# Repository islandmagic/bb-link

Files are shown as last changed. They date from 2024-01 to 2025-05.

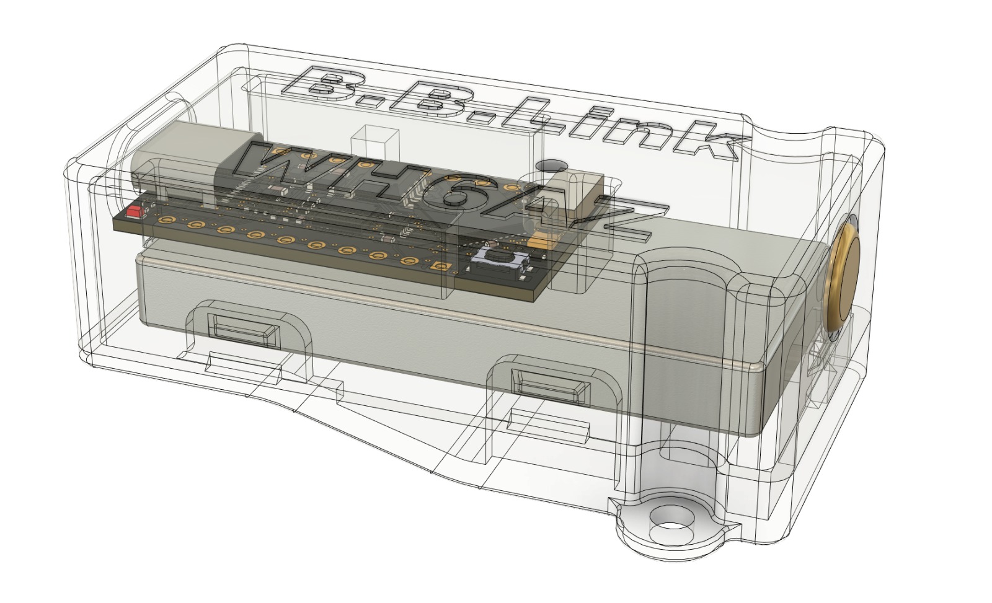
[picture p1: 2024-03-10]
enclosure/contribs/F4LFJ/BB-Link_case_01.jpeg

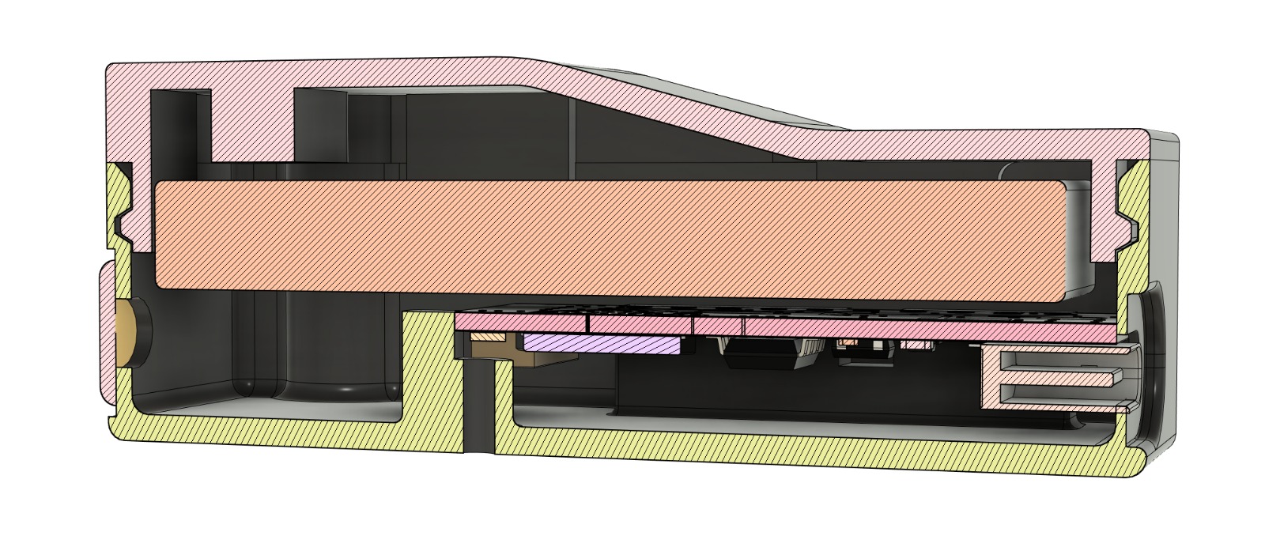
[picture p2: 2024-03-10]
enclosure/contribs/F4LFJ/BB-Link_case_06.jpeg

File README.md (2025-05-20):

<hr/>

### Psst… skip the soldering.

<a href="https://islandmagic.co/products/B-B-Link-Adapter-p629580960?utm_campaign=diy&utm_medium=web&utm_source=github">
              
</a>
              <br/>
 
### 👉 <a href="https://islandmagic.co/products/B-B-Link-Adapter-p629580960?utm_campaign=diy&utm_medium=web&utm_source=github">Check out</a> the sleek ready-made version that plugs directly into USB-C!

<hr/>

# B.B. Link, the BLE to Bluetooth Classic adapter for Kenwood TH-D74/5 Radios

Some devices, like the Kenwood TH-D75 radio only support Bluetooth Classic serial profile. iOS devices only support Bluetooth Low Energy (BLE). They are not compatible and as such, you can't pair those devices together. This code provides a way to create an adapter that can interface a device that exposes a serial profile over Bluetooth Classic, to an iOS device via BLE. Its main purpose is to enable iOS app that supports AX.25 packet like RadioMail or APRS.fi to use the TNC built in the radio as a modem.

For a detailed "how-to build" this adapter, watch this video: 

Watch the video (https://player.mux.com/SZQsZnBJDJf4GMUrTRxJ386tSpsIlRP02yfmXZr79TKg)

After you're done, come back and follow the instructions here as they are continually updated.

## Hardware

The adapter is based on the ESP32 microcontroller, which provides support for both Bluetooth Classic and Bluetooth Low Energy (BLE). There is specialized code tailored for the [TinyPICO](https://www.tinypico.com) development board, which serves as the standard implementation. This code can be altered to work with other ESP32-based boards as needed.

**Note: Compatibility is limited to ESP32 microcontroller. Boards like the TinyS3, which use the ESP32-S3 chip, do not support Bluetooth Classic. If you don't use the TinyPICO, make sure to choose a board that features the ESP32 microcontroller.**

### Material

1. TinyPICO [Buy](https://unexpectedmaker.com/shop.html#!/TinyPICO/p/577111313/category=154494282)
2. 600 mAh LiPo Battery model 602248 (6x22x48mm) [Buy](https://www.aliexpress.us/item/2251832520607268.html)
3. 3D Printed case
4. Brad fastener as touch button (8mm head)

### Power Options

The adapter can be powered via USB, such as through a USB adapter or a portable power bank, or alternatively, it can be connected to a LiPo battery for use on the go. The TinyPICO will charge the battery when plugged into USB.

### Capacitive Touch Button

The installation of a capacitive touch button is not required but recommended if you need an on/off switch while using a LiPo battery. To install, connect a wire to pin number 4 on the TinyPICO board; this will serve as the on/off control.

### Cases

You can 3D print a case to house the battery and the board. Here are a couple of option that attach via the mounting holes for the belt clip.

1. Horizontal

This is the orignal design from WH6AZ, functional but primitive. Can work as a stand alone box if you don't feel like attaching to the radio.

https://github.com/islandmagic/bb-link/tree/master/enclosure

2. Vertical

This design is a beautiful contribution from F4LFJ. It features a slick design that allows the case to attach vertically. There is enough clearance to insert and remove the battery from the radio.

https://github.com/islandmagic/bb-link/tree/master/enclosure/contribs/F4LFJ

## Software

1. Install Arduino IDE 2.x [https://www.arduino.cc](https://www.arduino.cc)
1. Add additional library source in Arduino IDE. Settings > Additional board manager URLs: `https://raw.githubusercontent.com/espressif/arduino-esp32/gh-pages/package_esp32_index.json`
1. Install the esp32 by Espressif Systems board library. This code has been tested with version 2.0.15.
1. Install the TinyPICO helper library
1. Install FreeRTOS library
1. Install ArduinoQueue library
1. Install ArduinoLog library
1. Clone this repo
1. Flash the code to the TinyPICO board
1. Download [B.B. Link Configurator](https://apps.apple.com/us/app/b-b-link-configurator/id6476163710) app on your phone
1. Download RadioMail on your phone [https://radiomail.app](https://radiomail.app)

### Rig Control

By default, the adapter will set the radio to KISS mode and automatically respond to RadioMail's instructions to switch frequencies, enabling seamless operation. If you prefer the adapter not to alter radio settings during use, toggle off the 'Control Frequency' option in the configurator app.

## Operating Instructions

### Powering On

1. Wake the adapter by briefly pressing the touch button. An amber light will indicate that it is awake.

### Pairing with a Radio (one time only)

1. Turn on adapter
1. Open B.B. Link Configurator app on your  phone
1. After a few seconds, `B.B. Link` appears in the list of nearby adapters. Select it.
1. Set the radio in Bluetooth discovery mode. Navigate to 'Menu -> Bluetooth -> Pairing Mode' on the radio.
1. Tap 'Paired Radio' on B.B. Link app
1. Wait a few seconds, the name of your radio should appear in the list. Select it.
1. After a few seconds a PIN prompt should appear on the radio. Press 'OK' to accept. This step is only necessary once; afterwards, the adapter will automatically try to reconnect with the radio.
1. Successful pairing is indicated by a breathing blue LED on the adapter.

### Pairing with iPhone or iPad

1. Make sure B.B. Link Configurator app is fully closed
1. Open the RadioMail app. Proceed to 'Settings -> KISS TNC Modem -> Default TNC'.
1. `B.B. Link` should be visible in the discovery screen.
1. Select `B.B. Link` and tap 'Done'.
1. Navigate to the connection screen and choose a packet station.
1. A solid blue LED on the adapter signals that RadioMail has connected. Red and green LEDs will flash to indicate data transmission and reception.

### Powering Off

- The adapter will shut off automatically after 5 minutes when not in use on battery power. It stays on indefinitely if USB power is detected.
- To manually turn off the adapter, press and hold the touch button until the LED blinks amber, then release.

### User Interface

#### Touch Button Functions

- **Short Press**: Wake the adapter or check the battery status when idle.
- **Long Press**: Turn off the adapter.

#### LED Indicator

The dotstar tri-color LED is used to indicate various states:

- 🟠: Idle, adapter waiting to pair
- 🔵 (slow flash): Adapter scanning for radio
- 🔵 (breathing): Idle, paired with radio
- 🔵: Ready, radio and iOS device paired
- 🟠 (fast blink): Shutting down

Data Activity:

- 🟢: Rx (Receiving)
- 🔴: Tx (Transmitting)
- 🟣: Rx/Tx (Both Receiving and Transmitting)

Error Conditions:

- 🔴 (fast blink): Low battery immediate shutdown
- 🔴 (slow flash): Fatal error, must reset

Battery Status Indicators:

- 🟢: Battery full
- 🟢 (fast blink): Battery low

#### Battery Indicator

The charge level of a LiPO battery can be difficult to determine without additional circuitry due to their non-linear discharge curve. A basic battery indicator is provided based on the battery voltage level:

1. Upon waking up, the adapter displays the battery level for a few seconds. A solid green light indicates the battery is considered full, while a flashing green light suggests the battery needs charging.
1. When the adapter is idle (indicated by an amber LED), a short tap will activate the battery level display.

### Battery Saver

To save energy, the adapter automatically enters a low-power sleep mode after a certain period of not being used, for instance, when no phone is connected, during which it consumes approximately 40 µA. While active, the adapter's power consumption is around 140 mA, allowing for continuous operation for up to 4 hours on a 600 mAh battery. In standby mode, with no active bluetooth connection, it uses about 80 mA. Additionally, the sleep feature is disabled when the adapter is connected to USB power, ensuring that the adapter can stay on for longer durations and can be used while it is being charged.

If the battery voltage falls to a critical level, the adapter will automatically shut down to prevent damage to the circuit.

### Factory Reset

You can reset the adapter to its default configuration. This will clear the list of previously paired devices and restoring default settings. Simply tap 'Reset Adapter' in the configurator app.

Alternatively, you can reset the adapter by connecting it to a computer. Here's how to do it:

1. Launch the Arduino IDE on your PC.
1. Connect the adapter to your PC using a USB cable.
1. Navigate to the Serial Monitor within the IDE.
1. Type `R` into the Serial Monitor and send the command.
1. Monitor the response in the Serial Monitor which will confirm the clearing of the previously paired devices.
1. After the process is complete, disconnect the adapter from your PC.

## Troubleshooting

* If the adapter connects to the radio but the radio does not transmit, check the TNC settings. Go to Menu > Configuration > Interface > KISS (983) and set it to Bluetooth.

## Known Issues

1. The ESP32 library is limited to discovering Bluetooth Classic devices exclusively prior to establishing any connections. After connecting with a device, the discovery capability is no longer available. To initiate a new scan, the adapter must be rebooted. If you intend to pair with a different radio, ensure that the radio previously paired with is turned off before powering on the adapter. If not, the adapter will automatically re-establish a connection with the previously paired radio, preventing it from discovering new radios.

## How to Contribute

This project is open source, so everyone's contribution is welcome. Here's a quick guide to get started:

* **Share**: If you build your own adapter, share it online! Post photos, write a blog post, or create a tutorial video to show others how it's done.
* **Update Documentation**: Help improve or correct the documentation. Fork the repo, make your updates, and submit a pull request.
* **Submit Change Requests**: If you're developing a new feature or bug fix, fork the repository, create a new branch for your changes, and submit a pull request with a clear description of your modifications.
* **Write Good Issue Reports**: If you encounter bugs or have feature suggestions, please submit an issue report with a clear title, a detailed description, and steps to reproduce the issue if it's a bug.

The source code for the [Configurator](https://github.com/islandmagic/ios-bblink-config) app is available as well.

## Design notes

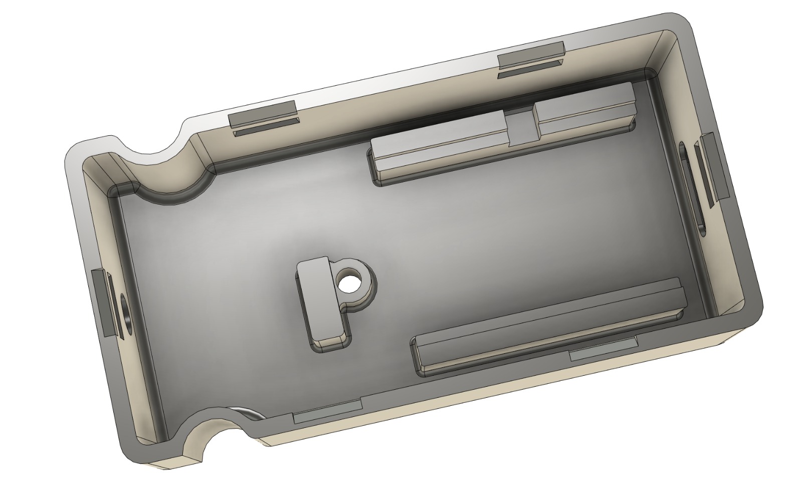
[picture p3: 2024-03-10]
enclosure/contribs/F4LFJ/BB-Link_case_03.jpeg

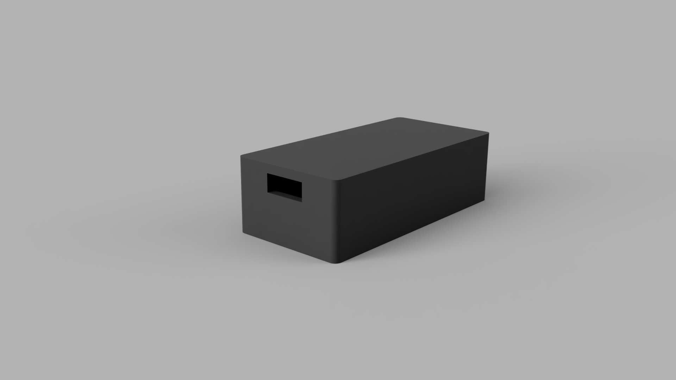
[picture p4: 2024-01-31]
enclosure/B.B. Link enclosure.jpg

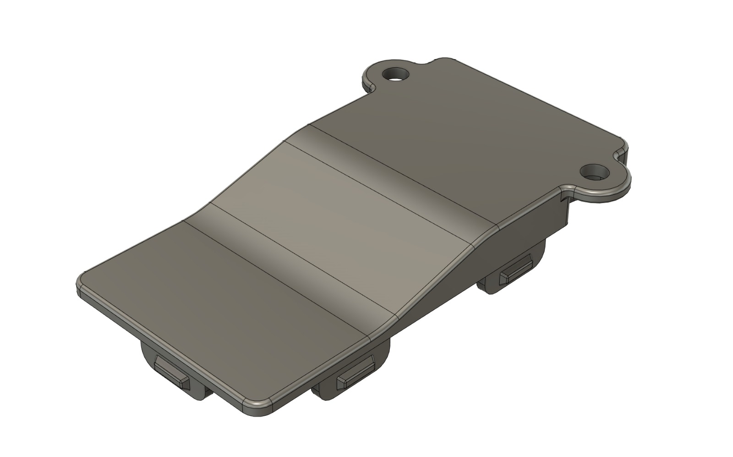
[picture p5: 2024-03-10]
enclosure/contribs/F4LFJ/BB-Link_case_04.jpeg

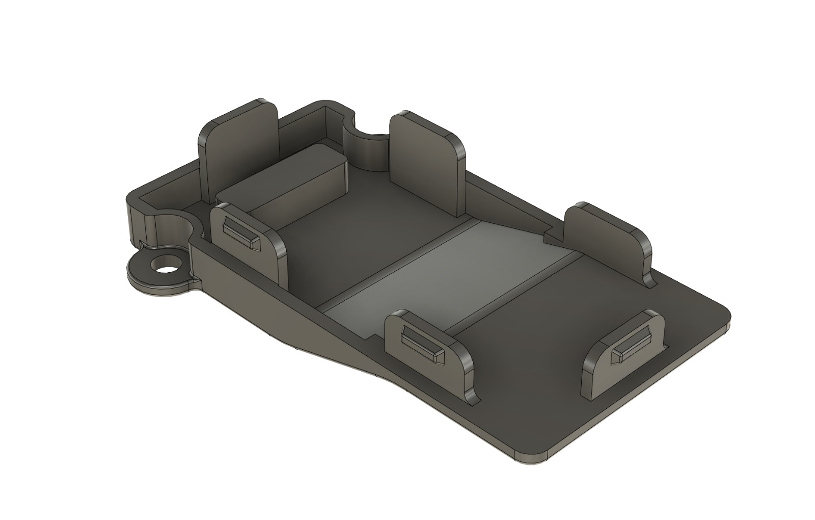
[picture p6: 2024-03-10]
enclosure/contribs/F4LFJ/BB-Link_case_05.jpeg

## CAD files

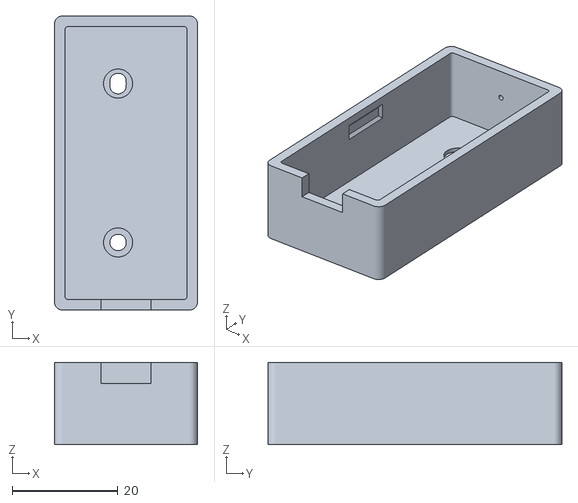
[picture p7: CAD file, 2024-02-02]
enclosure/B.B. Link v3 - Enclosure.stl
27.0 x 55.5 x 15.5

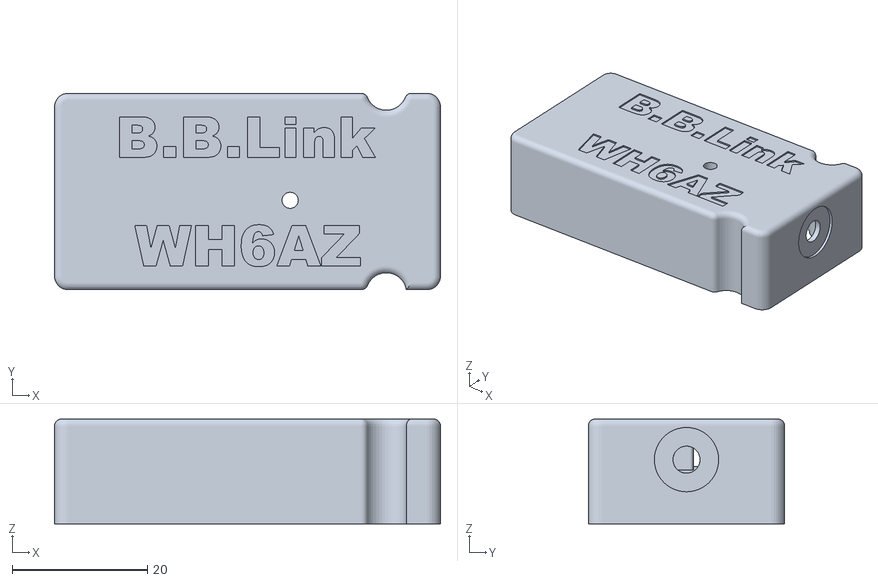
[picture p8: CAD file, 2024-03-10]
enclosure/contribs/F4LFJ/BB-link part A v5.stl
57.0 x 29.0 x 15.5

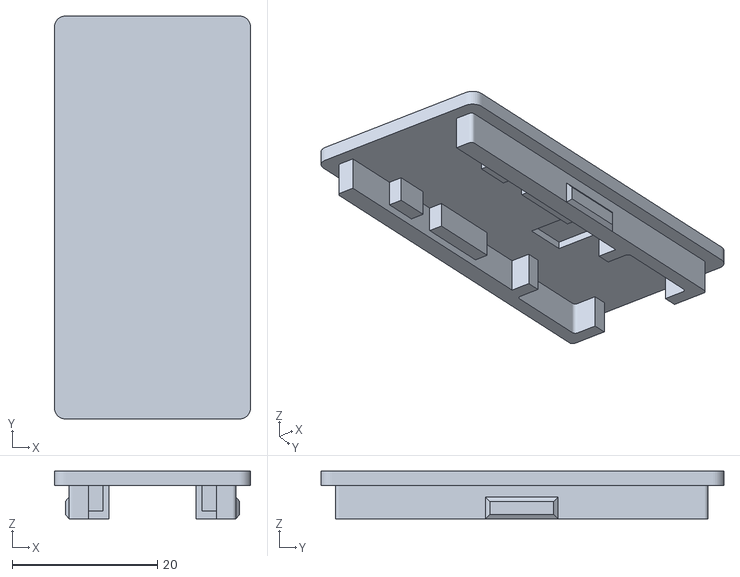
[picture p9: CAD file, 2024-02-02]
enclosure/B.B. Link v3 - Lid.stl
27.0 x 55.5 x 6.56

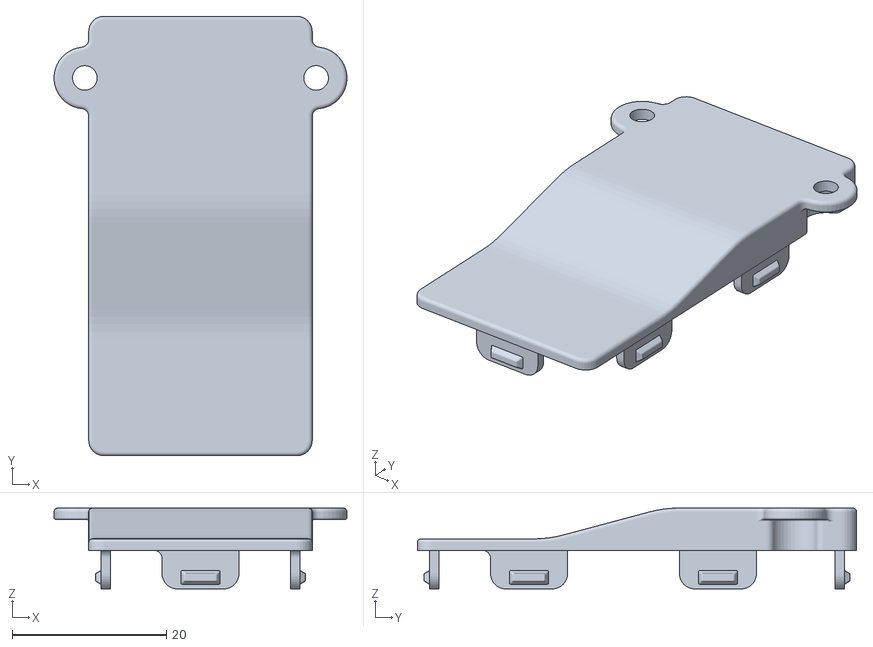
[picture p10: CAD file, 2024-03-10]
enclosure/contribs/F4LFJ/BB-link part B v5.stl
38.0 x 57.0 x 10.5

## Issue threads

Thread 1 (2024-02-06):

enclosure STL designs

swiftraccoon, 2024-02-06:
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

Note the size in mm.

commit 33436c0

georges, 2024-02-06:
The enclosure that also double as a swimming pool.

I'm not seeing that. Did you make sure your user preferences are set to mm?

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

swiftraccoon, 2024-02-06:
Yeah, the settings were correct.

I see the problem now, however. You cannot right click "Save Link As". You must go the file in GitHub directly and then click the "Download Raw File" button. My apologies!

Closed 2024-02-06.

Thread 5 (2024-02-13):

B.B.Link Configurator Update Firmware Link

giminok, 2024-02-13:
In B.B.LinkConfigurator app - it shows the Firmware Version as 0.7.3.  The "Update Firmware" link is active below it.

When "Update Firmware" link is pressed, the dialog shows "Update Firmware to 0.7.2".

As it shows the adapter is on 0.7.3 the firmware update isn't needed so Update Firmware link should be disabled?   Only adding this if that can cause a problem otherwise do not think it matters once a radio is paired.

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

georges, 2024-02-14:
Thanks for the detailed report. There are a few things at play here.

0. The current OTA firmware is set to 0.7.2

1. There is a toggle in Settings -> B.B. Link Configurator -> Experimental that allows you to toggle a Beta channel for firmware updates. The Beta channel will post pre-release version as they are being tested. This allows me to test OTA update without disrupting anything. Usually that channel will have one version up, for instance now it's 0.7.3

2. Because of the Beta channel, I wanted a way to allow downgrade to released firmware. For example someone may try the Beta channel, realize it's breaking something and need to go back down. As such, I decided to allow firmware upgrade as long as the installed version is different than the available OTA version (could be upgrade or downgrade)

I could clean up the UI to be a more descriptive to inform the user they will downgrade in that case.

georges, 2024-02-14:
And to answer the rest of your question, firmware upgrade should not affect radio pairing, unless of course some new code gets introduce that would require a repairing for some reason.

giminok, 2024-02-14:
@georges Thank you for a quick reply.  The downgrade makes a lot of sense.  Appreciate the details.

Closed 2024-02-14.

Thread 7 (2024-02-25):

TinyPICO TP01 USB C

Thuff256, 2024-02-25:
I flashed my TinyPICO with the Mac version of the Arduino IDE 2.3.3 and I got what looked like it downloaded to work.

Leaving...
Hard resetting via RTS pin...

Unfortunately, the amber LED never came on indicating the TinyPICO reset and rebooted.  When I removed the USBC cable and reapplied it would not come out of the state it was stuck in.  I tried two more times to flash the board with no change.

It did say Installed ArduinoQueue: 1.2.5
FreeRTOS:11.0.1-5
TinyPICO Helper Library:1.4.0
esp32.2.0.14

I am sure I missed something so please let me know what I can do to get this working.

If you need anything else please let me know to get this working.

Tim KM4ESU

Thuff256, 2024-02-25:
I missed the ArduinoLog so I added it and flashed the board.  I check the serial Monitor and this is what I saw.
����������������������������������������������������������������������������������������������
I am set a 115200 Baud.

georges, 2024-02-25:
Yes the board should come up at 115200 baud. If you're seeing gibberish it means that the speed is not setup properly, perhaps the code is not starting. Try to change the serial monitor speed down to 9600 baud. Press reset on the board and see if you get some output. It should show you what's happening on the board, either the default program running, or something else.

Also, please include the complete output of the flashing window just in case something is not working correctly during that phase.

Thuff256, 2024-02-25:
Reset got the serial to work at 115200.  Please let me know what to do next.

Thank you!
Tim

rst:0x1 (POWERON_RESET),boot:0x13 (SPI_FAST_FLASH_BOOT)
configsip: 188777542, SPIWP:0xee
clk_drv:0x00,q_drv:0x00,d_drv:0x00,cs0_drv:0x00,hd_drv:0x00,wp_drv:0x00
mode:DIO, clock div:1
load:0x3fff0030,len:1344
load:0x40078000,len:13964
load:0x40080400,len:3600
entry 0x400805f0

georges, 2024-02-25:
This is what you should see on a properly flashed TinyPICO

```
rst:0x1 (POWERON_RESET),boot:0x13 (SPI_FAST_FLASH_BOOT)
configsip: 188777542, SPIWP:0xee
clk_drv:0x00,q_drv:0x00,d_drv:0x00,cs0_drv:0x00,hd_drv:0x00,wp_drv:0x00
mode:DIO, clock div:1
load:0x3fff0030,len:1344
load:0x40078000,len:13964
load:0x40080400,len:3600
entry 0x400805f0

 ___   ___     _    _      _
| _ ) | _ )   | |  (_)_ _ | |__
| _ \_| _ \_  | |__| | ' \| / /
|___(_)___(_) |____|_|_||_|_\_\

Booting up B.B. Link v0.7.4 on TinyPICO v3.0

Heap free: 232100, usage: 11 %
Flash size: 1190704, total: 1310720, usage: 90 %
Log level: INFO
```

It appears that your board is not executing the setup() properly for some reason. Maybe it's defective? Have you tried flashing as simple hello world and see if it works?

Thuff256, 2024-02-25:
I tried two different boards with the same result. They came from the Unexpected Maker in Australia. I practiced good ESD too. I guess I can order 2 more to see but the lights come on and its not dead.

georges, 2024-02-25:
Mmm, I'd say it's probably something else. When you say the lights come on, are you talking about the top left blue and the top right blinking yellow?

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

And from what you said earlier, the tri-color on the bottom is not coming on for you?

georges, 2024-02-25:
And just to confirm, when you flashed you selected TinyPICO and the wchusbserial port?
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

Thuff256, 2024-02-25:
Yes, the bottom blue and amber come on but the tri-color does not.  This is the same on the board you show.  I do have an earlier USB-C as well but until I know these two are dead I will wait in it.  The computer is an M1 Mac with an Apple USBC Thunderbolt data cable to program the board.

georges, 2024-02-25:
Can you try to remove that line

https://github.com/islandmagic/bb-link/blob/51684739e3f17b9a8a742f20d39347f30b24f7e4/src/bb-link/bb-link.ino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

and reflash?

Thuff256, 2024-02-25:
Yes, that is the board and port note the amber LED by the USB-C connector is blinking and the blue is on.

Thuff256, 2024-02-25:
rst:0x1 (POWERON_RESET),boot:0x13 (SPI_FAST_FLASH_BOOT)
configsip: 188777542, SPIWP:0xee
clk_drv:0x00,q_drv:0x00,d_drv:0x00,cs0_drv:0x00,hd_drv:0x00,wp_drv:0x00
mode:DIO, clock div:1
load:0x3fff0030,len:1344
load:0x40078000,

georges, 2024-02-26:
In your Arduino IDE, find the file named `bb-link.ino` and scroll to line 24

Thuff256, 2024-02-26:
I tried to edit line 24 but the code is read-only.  I am not sure if I can pull it into an editor and edit then past the whole thing into the Arduino IDE.

Tim

Thuff256, 2024-02-26:
I did test the third board all USB-C but that one is older none seem to work.  I am not sure what I am doing wrong but I do hope to get them working.  I have 2 D74 that need this one for traveling the other home.

I hope we can find out why they do not work.

Tim

georges, 2024-02-26:
There should not be anything involving GitHub, you just need to edit your local file from within the Arduino IDE.

Thuff256, 2024-02-26:
This may be the problem I can't find the local file?  it should be in /Users/timhuffaker/Documnets/Aruino I do see the libraries but not the sketch file.  Is it hidden?

georges, 2024-02-26:
The ArduinoIDE should have tabs open with files.

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

If bb-link.ino does not show, use the 3-dot menu to open it.

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

Thuff256, 2024-02-26:
Well, I found the problem your GetHub file is not loading in the download and there is nothing in the three dots.  I did follow your youtube and copied the file but I do not know why the file is not loaded.  Should I click the raw button and copy the file?   This is what I do for Raspberry Pi's to download code.

georges, 2024-02-26:
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

1. On GitHub, click green button, select download zip.
2. Expand the zip in your local directory
3. Double click `bb-link.ino` in `bb-link-master/src/bb-link` folder
4. Arduino IDE should open an load all the files for you

You probably flashed an empty file to the board, so try to flash these file first before trying to remove the line I had suggested.

Thuff256, 2024-02-26:
Success I have an amber LED.  Not to continue testing and add the battery.  For you and some humor, my son came in and I asked him for help.  He did what you showed before you showed it and that got it working.  Then I read your post and LOL.

Thank you for your help!
Tim

Closed 2024-02-26.

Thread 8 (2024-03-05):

Compilation error: ArduinoLog.h: No such file or directory

F4LFJ, 2024-03-05:
Hi Georges,

Not an issue anymore but here is what I have encountered at the first compilation:

During the first compilation I've got the following error:
Compilation error: ArduinoLog.h: No such file or directory

Line 15 of the ino file reference it: #include <ArduinoLog.h>

The installation of the ArduinoLog library is not mentioned in your video.
So I've installed the v1.1.1 by Thijs Elenbaas

I was able to compile and upload the file to the board.
The BB-link apps see the board, it works!
I just wait few days to receive my Th-D75.

Thanks for this great job!

73, Claude, F4LFJ

georges, 2024-03-09:
Thanks Claude. Yes the logging has been added since the video. The README has been updated so always a good idea to check that too. Glad you got it running.

F4LFJ, 2024-03-09:
Great! Thanks for the feedback George!

Closed 2024-03-09.

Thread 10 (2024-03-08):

TH-D75E doesn't transmit

F4LFJ, 2024-03-08:
Hello,

I've used the components described in this repository and have compiled the latest ino file.
On my phone the firmware version is described as v0.7.4

Radiomail/BB-link would switch the HT to the selected frequency and Kiss mode but the TH-D75 is not transmitting.
I can see the led on the Tinypico board blinking red but no tranmission on the HT.

Once the transmission request cancelled, BB-link restore the original frequency and mode.

TH-D75E
Tinypico USB-C
iPhone 11, iOS 17.3.1
Radiomail 1.3.1 (7)
BB-link 1.0.1 (2), firmware 0.7.4

73,
Claude, F4LFJ

georges, 2024-03-09:
If the adapter connects to the radio but the radio does not transmit, check the TNC settings.
Go to Menu > Configuration > Interface > KISS (983) and set it to Bluetooth.

F4LFJ, 2024-03-09:
Thanks, it was that!
All working know...just have to find a station that I can work with.

By the way, I made a case that can be mounted at the place on the belt clip.
I can share the STL files.

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

georges, 2024-03-10:
Great to hear you're up and running. Fantastic job on the case. I had originally thought of going vertical, but clearly lack the skills to make it be as streamline as your design.

Do you mind sending a pull request with the .stl files in the enclosure directory and I'll be more than happy to merge this in.

F4LFJ, 2024-03-10:
Great you like the case!
No sure how to pull a request to add stl files only, so you should have received a email at your winlink address that contain a link to a dropbox folder.

Regards,
Claude

georges, 2024-03-10:
Link did not seem to have gone thru. Can you post it here? Thanks. On Mar 10, 2024, at 03:10, F4LFJ ***@***.***> wrote:
Great you like the case!
No sure how to pull a request to add stl files only, so you should have received a email at your winlink address that contain a link to a dropbox folder.
Regards,
Claude

—Reply to this email directly, view it on GitHub, or unsubscribe.You are receiving this because you commented.Message ID: ***@***.***>

F4LFJ, 2024-03-10:
Ok,this link should work:
[https://www.dropbox.com/scl/fo/olg7sb9cd9zcofyi6ggig/h?rlkey=3vxm2wyfdxv4gsjwn9tiy6y8t&dl=0](url)

georges, 2024-03-10:
Perfect. I've updated the repo with your files. I'm going to have to print one of those, they look cool. Merci Claude!

F4LFJ, 2024-03-11:
De rien! Eventuellement je peux t'envoyer une paire de ses boitiers.

Closed 2024-03-10.

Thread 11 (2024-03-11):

Feature Request: Output TX/RX Pakets via serial console

9V1LH, 2024-03-11:
Aloha from Singapore!

For debugging purposes, it would be beneficial if the received and transmitted packets were sent to the serial output.

73 & 55 de Stephan 9V1LH / DG1BGS

georges, 2024-03-15:
What format would you expect the packet to be in? KISS frames in hex format?

9V1LH, 2024-03-15:
In the best case it would show the packets in a readable format like the raw packets you would see in the aprs.fi app

georges, 2024-03-17:
That would require needing to decode AX.25 protocol to interpret the payload. Fun, but maybe overkill for this adapter. What would you expect to get that you can't get in aprs.fi?

9V1LH, 2024-03-22:
I agree. I had another idea and for this, I would also need to decode the AX.25 protokoll. However, I wasn't paying too much attention and thought that the radio already sent the KISS packets which could be easily been written to the serial output. Maybe I take a closer look at it when I have some spare time.

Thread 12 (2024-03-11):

Feature Request: Convert Raw-Pakets to KISS-Pakets

9V1LH, 2024-03-11:
Aloha from Singapore!

I have another use case where I want the TH-D74 to remain in APRS standalone mode. However, in this mode, you can still output the raw packets via Bluetooth. It would be great if we could convert them into KISS packets and send them to the aprs.fi iOS app to continue displaying the received stations on the map.

73 & 55 de Stephan 9V1LH / DG1BGS

georges, 2024-03-15:
Interesting idea. I'll have to research this some more. However right now, when a device connects to B.B. Link via BLE, it automatically puts the radio in KISS mode because presumably a client is wanting to talk to the TNC. There would need some extra logic to make this conditional.

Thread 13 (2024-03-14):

feature request: M5StickC Plus support

fanlessfan, 2024-03-14:
Hello,

Could we add support for M5StickC Plus (ESP32-PICO-D4, with battery, buttons and screen)?

https://shop.m5stack.com/products/m5stickc-plus-esp32-pico-mini-iot-development-kit

thx
VA3EMQ

fanlessfan, 2024-03-14:
or add support for Atom Lite (Infra-Red LED, RGB LED, buttons) and Atom Matrix
https://shop.m5stack.com/products/atom-lite-esp32-development-kit
https://shop.m5stack.com/products/atom-matrix-esp32-development-kit

georges, 2024-03-15:
The M5StickC looks like an interesting all in one device. I don't have access to any of these devices, but if someone wants to open a pull request with proper support, I'll be happy to review.

fanlessfan, 2024-04-03:
Is there anyone can update the code to add the support for M5StickC Plus? Here is the schematic [https://m5stack.oss-cn-shenzhen.aliyuncs.com/resource/docs/schematic/Core/M5StickC_Plus/StickC_Plus_20200616.pdf](url)

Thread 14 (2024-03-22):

ArduinoLog.h: No such file or directory

rodzillanh, 2024-03-22:
when I verify I get to following error

D:\downloads\bb-link-master\bb-link-master\src\bb-link\bb-link.ino:15:10: fatal error: ArduinoLog.h: No such file or directory
 #include <ArduinoLog.h>
          ^~~~~~~~~~~~~~
compilation terminated.
exit status 1

Compilation error: ArduinoLog.h: No such file or directory

rodzillanh, 2024-03-22:
I figured it out

Closed 2024-03-22.

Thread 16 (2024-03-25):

TinyPICO board sleeping even when USB-C powered

ftmiranda, 2024-03-25:
Hello,
I followed this YouTube video https://www.youtube.com/watch?v=xLze6qDOLww&t=1127s and the solution proposed works extremely well.
Since I did not want to bother with the internal battery, I decided just to power the board with the USB-C. All works well, until you power off your D75, close the RadioMail on your iPhone and you keep the TinyPICO board powered by a large PowerBank... after a while, the board will enter in some sort of sleep mode. If I power back on my D75, and open the RadioMail, try to connect using packet.... nothing... the connection times out. If I unplug the USB-C and plug it again, after a few seconds I can re-check my email using RadioMail and all works great again.
Is there any way to prevent the board from sleeping at all when powered by the USB-C? Thank you

georges, 2024-03-25:
Can you plug the TinyPICO into a computer instead of power bank and open the serial console (easiest is to open in ArduinoIDE). After a while, you should see something like:

```
I: Idle for 300 s
I: On USB power, stay awake
```

ftmiranda, 2024-03-25:
Something I  noticed, I had a firmware update today, 0.74-> 0.75
After this update, I left the board connected to a power bank for hours, then I turned on my D75, after 5 seconds it connected to the pico board, and RadioMail just worked. Not sure if the firmware update did the trick or if I had a glitch before, but now it seems to work just fine!! Thank you

Closed 2024-03-26.

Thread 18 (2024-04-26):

Constantly losing BLE connection

2e0wkw, 2024-04-26:
In the B.B.Link app as soon as i move away from the page that shows the paired device the app reports that it has lost BLE connection. I am sure it hasn't.

E.G i connect my iPhone and TH-D75 and go to aprs.fi to send a message when i return to B.B.Link app it reports that it has lost the BLE connection

Setup:
TinyPico with latest firmware built via Arduini IDE 2.3.2 and esp32 2.0.11
TH-D75
iPhone 14 Pro with IOS 17.4.1

georges, 2024-04-28:
It's by design. With BLE, there can only be one application connected. The B.B. Link configurator app is meant to only be run seldomly to setup pairing with a radio. When the app looses focus, it automatically disconnects so that another app (APRS.fi in your case) can connect.

Closed 2024-05-30.

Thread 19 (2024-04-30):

can't get the TinyPICO to work

wptracy, 2024-04-30:
I have Arduino EDI 2.3.2 installed on the PC.

The sketch that is created is sketch_apr29a, but I don't know how it got that name.

I've got a paperclip connected to pin 4, but touching it long or short touch doesn't do anything.

I don't have a battery connected, but I do have the USB-C cable connecting the TinyPICO to the PC.

I figured that should power the board like the battery would.

I've got the following libraries installed but can't get the TinyPICO to work.
The amber light near the reset button and antenna, never comes on.
The blue light near the USB-C connector is bright and steady.
The amber light near the USB-C connector is dim and flashing (fast).

Here are the installed libraries:
esp32 by Espressif Systems 2.0.15
TinyPICO Helper Library by UnexpectedMaker 1.4.0
FreeRTOS by Richard Barry <info@freertos.org> 11.1.0.0
ArduinoQueue by Einar Amason by <einsiarna@gmail.com> 1.2.5
ArduinoLog by Thijs Elenbaas 1.1.1

I've compiled and uploaded to the TinyPICO and here is the log Output:
```
Sketch uses 257017 bytes (19%) of program storage space. Maximum is 1310720 bytes.
Global variables use 21168 bytes (6%) of dynamic memory, leaving 306512 bytes for local variables. Maximum is 327680 bytes.
esptool.py v4.5.1
Serial port COM3
Connecting....
Chip is ESP32-PICO-D4 (revision v1.1)
Features: WiFi, BT, Dual Core, 240MHz, Embedded Flash, VRef calibration in efuse, Coding Scheme None
Crystal is 40MHz
MAC: 64:b7:08:90:a3:14
Uploading stub...
Running stub...
Stub running...
Changing baud rate to 921600
Changed.
Configuring flash size...
Erasing flash (this may take a while)...
Chip erase completed successfully in 1.7s
Compressed 18992 bytes to 13110...
Writing at 0x00001000... (100 %)
Wrote 18992 bytes (13110 compressed) at 0x00001000 in 0.3 seconds (effective 483.5 kbit/s)...
Hash of data verified.
Compressed 3072 bytes to 146...
Writing at 0x00008000... (100 %)
Wrote 3072 bytes (146 compressed) at 0x00008000 in 0.0 seconds (effective 837.9 kbit/s)...
Hash of data verified.
Compressed 8192 bytes to 47...
Writing at 0x0000e000... (100 %)
Wrote 8192 bytes (47 compressed) at 0x0000e000 in 0.1 seconds (effective 1185.7 kbit/s)...
Hash of data verified.
Compressed 257376 bytes to 139364...
Writing at 0x00010000... (11 %)
Writing at 0x0001ddb1... (22 %)
Writing at 0x00024e5b... (33 %)
Writing at 0x0002a0d4... (44 %)
Writing at 0x0002f754... (55 %)
Writing at 0x000384cf... (66 %)
Writing at 0x000410ec... (77 %)
Writing at 0x000466ff... (88 %)
Writing at 0x0004bf37... (100 %)
Wrote 257376 bytes (139364 compressed) at 0x00010000 in 2.3 seconds (effective 905.9 kbit/s)...
Hash of data verified.

Leaving...
Hard resetting via RTS pin...
```

wptracy, 2024-04-30:
Never mind.  I figured it out.
Download bb-link-master.zip.
uncompress it
Change directory to src/bb-link
Double click on bb-link.ino to install it.

wptracy, 2024-04-30:
I figured it out.  see my comment above

Closed 2024-04-30.

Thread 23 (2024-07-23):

“nil” and SSI?

Beavxx, 2024-07-23:
I got it all working. Went back to it later and the Configurator App no longer shows “BB Link” and SSI; it shows “nil” and SSI.

Re-flashed several times. Same. Not sure what caused it to go from working to “nil”

This is great; thank you for sharing this.

Thank you in advance for any help you can offer on this issue.

Beavxx, 2024-07-23:
I flashed a second TinyPico I had and it works fine. Perhaos a bad board? Odd.

Beavxx, 2024-07-24:
The build works great. Not sure why the first board doesn’t work. Thank you for sharing this, it was a lot fun and a great companion for the D74 and Radiomail.

Beavxx, 2024-07-24:
I’m going with bad dev board. Closing.

tan js

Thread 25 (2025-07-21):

Compilation error: conversion from 'String' to non-scalar type 'std::string' {aka 'std::__cxx11::basic_string<char>'} requested

agflyguy, 2025-07-21:
Getting a compile error with newer versions of the ESP32 library by Espressif.   Version 2.0.17 compiles the code without errors, but anything from 3.0.0 to 3.2.1 exhibits the error. Adapter.cpp & Bridge.cpp are referenced by the error.

I am just getting the environment setup while waiting for my boards.  Not sure if using 2.0.17 ESP32 libray will cause any issues with a working board.

These errors are produced using the Verify function in the 2.3.6 IDE.

XX/Downloads/bb-link-master/src/bb-link/Adapter.cpp: In member function 'virtual void Adapter::onWrite(BLECharacteristic*)':
XX/Downloads/bb-link-master/src/bb-link/Adapter.cpp:274:49: error: conversion from 'String' to non-scalar type 'std::string' {aka 'std::__cxx11::basic_string<char>'} requested
  274 |   std::string rxData = pCharacteristic->getValue();
      |                        ~~~~~~~~~~~~~~~~~~~~~~~~~^~
XX/Downloads/bb-link-master/src/bb-link/Bridge.cpp: In member function 'bool Bridge::initBTC()':
XX/Downloads/bb-link-master/src/bb-link/Bridge.cpp:178:12: error: 'class BluetoothSerial' has no member named 'setPin'
  178 |   btSerial.setPin("0000");
      |            ^~~~~~
XX/Downloads/bb-link-master/src/bb-link/Bridge.cpp: In member function 'virtual void Bridge::onWrite(BLECharacteristic*)':
XX/Downloads/bb-link-master/src/bb-link/Bridge.cpp:715:50: error: conversion from 'String' to non-scalar type 'std::string' {aka 'std::__cxx11::basic_string<char>'} requested
  715 |   std::string txValue = pCharacteristic->getValue();
      |                         ~~~~~~~~~~~~~~~~~~~~~~~~~^~
exit status 1

Compilation error: conversion from 'String' to non-scalar type 'std::string' {aka 'std::__cxx11::basic_string<char>'} requested

Closed 2025-09-22.

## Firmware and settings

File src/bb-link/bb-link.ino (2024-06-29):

/*
  (c) 2024 Island Magic Co. All Rights Reserved.

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
  This program is distributed in the hope that it will be useful,
  but WITHOUT ANY WARRANTY; without even the implied warranty of
  MERCHANTABILITY or FITNESS FOR A PARTICULAR PURPOSE.  See the
  GNU General Public License for more details.
*/

#include <ArduinoLog.h>
const char *logLevels[] = {"OFF", "FATAL", "ERROR", "WARNING", "INFO", "TRACE", "VERBOSE"};

#include "Adapter.h"
Adapter *adapter = nullptr;

void setup()
{
  // Slow down to save power
  setCpuFrequencyMhz(80); // 240, 160, 80

  Serial.begin(115200);
  delay(1000);

  // LOG_LEVEL_FATAL, LOG_LEVEL_ERROR, LOG_LEVEL_WARNING, LOG_LEVEL_INFO, LOG_LEVEL_TRACE, LOG_LEVEL_VERBOSE
  Log.begin(LOG_LEVEL_INFO, &Serial);
  Log.setPrefix(logPrintPrefix);

  adapter = new Adapter();

  Serial.println("\n ___   ___     _    _      _");
  Serial.println("| _ ) | _ )   | |  (_)_ _ | |__");
  Serial.println("| _ \\_| _ \\_  | |__| | ' \\| / /");
  Serial.println("|___(_)___(_) |____|_|_||_|_\\_\\\n");

  Serial.printf("Booting up %s v%d.%d.%d on %s v%d.%d\n\n", adapter->getAdapterName().c_str(), FIRMWARE_VERSION_MAJOR, FIRMWARE_VERSION_MINOR, FIRMWARE_VERSION_PATCH, HARDWARE_BOARD == hardware_board_tinypico ? "TinyPICO" : "Pico32", HARDWARE_VERSION_MAJOR, HARDWARE_VERSION_MINOR);

  Serial.printf("Heap free: %d, usage: %d %%\n", ESP.getFreeHeap(), 100 - (ESP.getFreeHeap() * 100) / ESP.getHeapSize());
  // ESP.getFreeSketchSpace() returns the total sketch space
  Serial.printf("Flash size: %d, total: %d, usage: %d %%\n", ESP.getSketchSize(), ESP.getFreeSketchSpace(), (ESP.getSketchSize() * 100) / ESP.getFreeSketchSpace());
  Serial.printf("CPU clock: %d Mhz\n", getCpuFrequencyMhz());
  Serial.printf("Log level: %s\n", logLevels[Log.getLevel()]);

  adapter->init();
}

void loop()
{
  adapter->perform();
}

void logPrintPrefix(Print* _logOutput, int logLevel)
{
  logPrintSetColor(_logOutput, logLevel);
  logPrintTimestamp(_logOutput);
}

void logPrintSetColor(Print* _logOutput, int logLevel)
{
  switch (logLevel)
  {
    case LOG_LEVEL_FATAL:
      _logOutput->print("\033[31m"); // red
      break;
    case LOG_LEVEL_ERROR:
      _logOutput->print("\033[31m"); // red
      break;
    case LOG_LEVEL_WARNING:
      _logOutput->print("\033[33m"); // yellow
      break;
    case LOG_LEVEL_INFO:
      _logOutput->print("\033[0m"); // default
      break;
    case LOG_LEVEL_TRACE:
      _logOutput->print("\033[36m"); // cyan
  }
}

void logPrintTimestamp(Print* _logOutput) 
{
  const unsigned long MSECS_PER_SEC       = 1000;
  const unsigned long SECS_PER_MIN        = 60;
  const unsigned long SECS_PER_HOUR       = 3600;
  const unsigned long SECS_PER_DAY        = 86400;
  const unsigned long msecs               =  millis();
  const unsigned long secs                =  msecs / MSECS_PER_SEC;
  const unsigned long milliseconds        =  msecs % MSECS_PER_SEC;
  const unsigned long seconds             =  secs  % SECS_PER_MIN ;
  const unsigned long minutes             = (secs  / SECS_PER_MIN) % SECS_PER_MIN;
  const unsigned long hours               = (secs  % SECS_PER_DAY) / SECS_PER_HOUR;

  char timestamp[20];
  sprintf(timestamp, "%02d:%02d:%02d.%03d ", hours, minutes, seconds, milliseconds);

  _logOutput->print(timestamp);
}

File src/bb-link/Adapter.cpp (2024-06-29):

#include <ArduinoLog.h>
#include "Adapter.h"

#define IDLE_TIME_TO_SLEEP 5 * 60 * 1000          // 5 min, time before shutting down when neither devices are connected
#define ACTION_FEEDBACK_DURATION 2000             // Duration for action feedback
#define LINGER_TIME_BEFORE_SHUTDOWN 2000          // Grace time for user to untouch button before sleeping, since touch would wake up device again
#define BATTERY_FULL_VOLTAGE 3.750                // Voltage above which to consider LiPo battery charged
#define BATTERY_MIN_VOLTAGE 3.500                 // Voltage below which esp32 should go to sleep as battery is going to rapidely drop its charge
#define SHOW_BATTERY_DURATION 3000                // Duration for battery indicator to stay on
#define BATTERY_WATCHGUARD_INTERVAL 3 * 60 * 1000 // Interval between battery check

#define VBUS_SENSE_GPIO 9

#define SERVICE_UUID_OTA "1A68D2B0-C2E4-453F-A2BB-B659D66CF442"
#define CHARACTERISTIC_UUID_OTA_FLASH "1A68D2B1-C2E4-453F-A2BB-B659D66CF442"
#define CHARACTERISTIC_UUID_OTA_IDENTITY "1A68D2B2-C2E4-453F-A2BB-B659D66CF442"

extern const char *logLevels[];

// AdapterState
Adapter::Adapter() : idleState(
                         [this]
                         { this->idleEnter(); },
                         [this]
                         { this->idleUpdate(); },
                         [this]
                         { this->idleExit(); }),
                     inUseState(
                         [this]
                         { this->inUseEnter(); },
                         [this]
                         { this->inUseUpdate(); },
                         [this]
                         { this->inUseExit(); }),
                     shutdownState(
                         [this]
                         { this->shutdownEnter(); },
                         [this]
                         { this->shutdownUpdate(); },
                         [this]
                         { this->shutdownExit(); }),
                     showBatteryState(
                         [this]
                         { this->showBatteryEnter(); },
                         [this]
                         { this->showBatteryUpdate(); },
                         [this]
                         { this->showBatteryExit(); }),
                     otaFlashState(
                         [this]
                         { this->otaFlashEnter(); },
                         [this]
                         { this->otaFlashUpdate(); },
                         [this]
                         { this->otaFlashExit(); }),
                     adapterStateMachine(idleState),
                     bridge(fetchAdapterName())
{
}

String Adapter::fetchAdapterName()
{
  String name = ADAPTER_NAME;
  Preferences preferences;

  if (preferences.begin(DEVICE_NAMESPACE, true))
  {
    name = preferences.getString(IDENTITY_KEY, ADAPTER_NAME);
    preferences.end();
  }
  return name;
}

String Adapter::getAdapterName()
{
  return bridge.getAdapterName();
}

void Adapter::init()
{
  Log.traceln("Adapter: init");
  pinMode(VBUS_SENSE_GPIO, INPUT);

  statusIndicator.init();
  touchButton.init();

  touchButton.setOnLongPressedCallback(std::bind(&Adapter::onLongPressed, this));
  touchButton.setOnShortPressedCallback(std::bind(&Adapter::onShortPressed, this));

#if defined(ARDUINO_TINYPICO)
  touchSleepWakeUpEnable(CAPACITIVE_TOUCH_INPUT_PIN, TOUCH_THRESHOLD);
#endif

  if (!bridge.init())
  {
    Log.fatalln("FATAL: Bridge init failed !!!!!");
    statusIndicator.set(error);
    while (true)
    {
      statusIndicator.render();
      delay(10);
    }
  }

  // Make sure bridge is initialized first
  initBLEOtaService();

  verifyFirmware();
}

void Adapter::verifyFirmware()
{
  Log.traceln("Checking firmware...");
  const esp_partition_t *running = esp_ota_get_running_partition();
  esp_ota_img_states_t ota_state;
  if (esp_ota_get_state_partition(running, &ota_state) == ESP_OK)
  {
    const char *otaState = ota_state == ESP_OTA_IMG_NEW              ? "ESP_OTA_IMG_NEW"
                           : ota_state == ESP_OTA_IMG_PENDING_VERIFY ? "ESP_OTA_IMG_PENDING_VERIFY"
                           : ota_state == ESP_OTA_IMG_VALID          ? "ESP_OTA_IMG_VALID"
                           : ota_state == ESP_OTA_IMG_INVALID        ? "ESP_OTA_IMG_INVALID"
                           : ota_state == ESP_OTA_IMG_ABORTED        ? "ESP_OTA_IMG_ABORTED"
                                                                     : "ESP_OTA_IMG_UNDEFINED";
    Log.infoln("OTA state: %s", otaState);

    if (ota_state == ESP_OTA_IMG_PENDING_VERIFY)
    {
      if (esp_ota_mark_app_valid_cancel_rollback() == ESP_OK)
      {
        Log.infoln("App is valid, rollback cancelled successfully");
      }
      else
      {
        Log.errorln("Failed to cancel rollback");
      }
    }
  }
  else
  {
    Log.warningln("OTA partition has no record in OTA data");
  }
}

void Adapter::initBLEOtaService()
{
  Log.traceln("Adapter: init BLE OTA service");

  // Create the BLE Service for OTA
  BLEService *pOtaService = bridge.getBLEServer()->createService(SERVICE_UUID_OTA);

  pOtaFlash = pOtaService->createCharacteristic(
      CHARACTERISTIC_UUID_OTA_FLASH,
      BLECharacteristic::PROPERTY_WRITE);

  pOtaIdentity = pOtaService->createCharacteristic(
      CHARACTERISTIC_UUID_OTA_IDENTITY,
      BLECharacteristic::PROPERTY_READ);

  pOtaFlash->addDescriptor(new BLE2902());

  pOtaFlash->setAccessPermissions(ESP_GATT_PERM_WRITE);
  pOtaIdentity->setAccessPermissions(ESP_GATT_PERM_READ);

  pOtaFlash->setCallbacks(this);

  uint8_t identity[6] = {HARDWARE_BOARD, HARDWARE_VERSION_MAJOR, HARDWARE_VERSION_MINOR, FIRMWARE_VERSION_MAJOR, FIRMWARE_VERSION_MINOR, FIRMWARE_VERSION_PATCH};
  pOtaIdentity->setValue(identity, 6);

  pOtaService->start();
}

void Adapter::perform()
{
  statusIndicator.render();
  if (!adapterStateMachine.isInState(otaFlashState))
  {
    touchButton.process();
    lowBatteryWatchguard();
  }
  adapterStateMachine.update();
}

void Adapter::updateSendReceiveStatus()
{
  if (bridge.isTx() && bridge.isRx())
  {
    // The adapter is full duplex and can receive and send at same time.
    statusIndicator.set(duplex);
  }
  else if (bridge.isRx())
  {
    statusIndicator.set(rx);
  }
  else if (bridge.isTx())
  {
    statusIndicator.set(tx);
  }
  else
  {
    statusIndicator.set(ready);
  }
}

void Adapter::lowBatteryWatchguard()
{
#if defined(ARDUINO_TINYPICO)
  unsigned long now = millis();
  if (now - lastBatteryCheck > BATTERY_WATCHGUARD_INTERVAL)
  {
    lastBatteryCheck = now;
    float level = tp.GetBatteryVoltage();
    Log.infoln("Battery voltage %F V", level);
    if (level < BATTERY_MIN_VOLTAGE)
    {
      Log.warningln("Voltage too low, initiating shutdown");
      shutdownReason = lowBattery;
      adapterStateMachine.transitionTo(shutdownState);
    }
  }
#endif
}
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

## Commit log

2024-01-31 Links to .stl files
2024-02-02 Refreshed designs
    [B.B. Link v3 - Enclosure.stl, B.B. Link v3 - Lid.stl, B.B. Link v38 - Enclosure.stl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]
2024-02-11 Ota update (#2)
    * Adds support for OTA firmware updates
    * Restructured code to abstract TinyPICO board specific functionality
    * Prevent BTC connection when BLE connected
    [Adapter.cpp, Bridge.cpp]
2024-02-12 Relax supervisor timeout. Fix bug preventing pairing.
    [Bridge.cpp]
2024-02-15 Unit tests (#6)
    * Added logger. Limit usb power detection to TinyPICO
    * Unit tests
    * Updated dependencies
2024-03-10 Contributed case .stl from F4LFJ
    [BB-link part A v5.stl, BB-link part B v5.stl]
2024-04-11 Fix problem where data was being sent before internal cmd fully processed. Add log colorization. (#17)
    [Bridge.cpp, THD7x.cpp, bb-link.ino]
2024-04-11 Bump esp32 library to 2.0.15. 2.0.14 is no longer available for download
2024-06-29 Store adapter identity in nvm (#20)
    Store device identity in nvm

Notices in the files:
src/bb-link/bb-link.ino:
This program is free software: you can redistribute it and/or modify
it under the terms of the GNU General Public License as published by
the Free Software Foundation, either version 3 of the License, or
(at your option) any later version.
